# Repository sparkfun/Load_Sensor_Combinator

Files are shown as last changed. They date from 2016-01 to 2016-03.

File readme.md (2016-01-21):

SparkFun Load Sensor Combinator
=============================

SparkFun Load Sensor Combinator

[*SparkFun Load Sensor Combinator (BOB-13281)*](https://www.sparkfun.com/products/13281)

Repository Contents
-------------------
* **/Hardware** - Eagle design files (.brd, .sch)

Documentation
--------------
* **[Hookup Guide](https://learn.sparkfun.com/tutorials/load-cell-amplifier-hx711-breakout-hookup-guideL)** - Basic hookup guide.
* **[SparkFun Fritzing repo](https://github.com/sparkfun/Fritzing_Parts)** - Fritzing diagrams for SparkFun products.
* **[SparkFun 3D Model repo](https://github.com/sparkfun/3D_Models)** - 3D models of SparkFun products. 

How to Use
----------
Combinator PCB

Combinator PCB in action

If you open up an electronic bathroom scale you’ll find a large rats nest of wires. The Load Sensor Combinator was created to combine the 12 wires found in a bathroom scale into the standard 4-wires that wheatstone bridge configuration.

This board also works with four of our individual [load sensors](https://www.sparkfun.com/products/10245). If you aren’t mechanically inclined we recommend purchasing an off-the-shelf bathroom scale and hacking the combinator into it rather than trying to design a base to properly mount four load sensors.

This board works great with our [Load Cell Amplifier](https://www.sparkfun.com/products/13230) breakout board. The five pins on the edge of the combinator line directly up to the five pins on the amplifier.

If your amplifier and supporting electronics are more than a few inches away from the scale an [RJ45 footprint](https://www.sparkfun.com/products/643) is provided. The 4 wheatstone pins (E+/E-/S+/S-) are connected to twisted pairs within a standard cheap ethernet cable. This allows the amplifier board to be placed many feet away from the scale itself.

The combinator board also includes a footprint for the [DS18B20 one wire temperature sensor](https://www.sparkfun.com/products/245). This allows the user to gather the temperature of the scale in case there is a large variance between the scale and the amplifier. These three pins are exposed to the RJ45 connection as well allowing remote temperature readings to be gathered over one twisted pair ethernet cable.

If you plan to use the RJ45 connection you will need to cut and strip the end of the ethernet cable you do not intend to plug into the combinator board. The wires of the exposed ethernet cable connect to the following pins on the combinator board:

* Combinator Pin = Ethernet cable wire color
* E+ = Brown
* E- = Brown white
* NC = Green
* A+ = Blue white
* A- = Blue
* 5V = Green white
* TEMP_DAT = Orange
* GND = Orange white

The NC pin is intentionally left *not connected*. For especially long cables the signals should be shielded against EMI. This is done by using the less common [shielded twisted pair](http://en.wikipedia.org/wiki/Twisted_pair#Cable_shielding) (STP) ethernet cable. The metal foil sheath of the cable creates a telescoping shield by connecting it to ground on the amplifier circuit, not on GND or any other pin on the combinator board.

License Information
-------------------

This product is _**open source**_! 

Please review the LICENSE.md file for license information. 

If you have any questions or concerns on licensing, please contact techsupport@sparkfun.com.

Distributed as-is; no warranty is given.

- Your friends at SparkFun.

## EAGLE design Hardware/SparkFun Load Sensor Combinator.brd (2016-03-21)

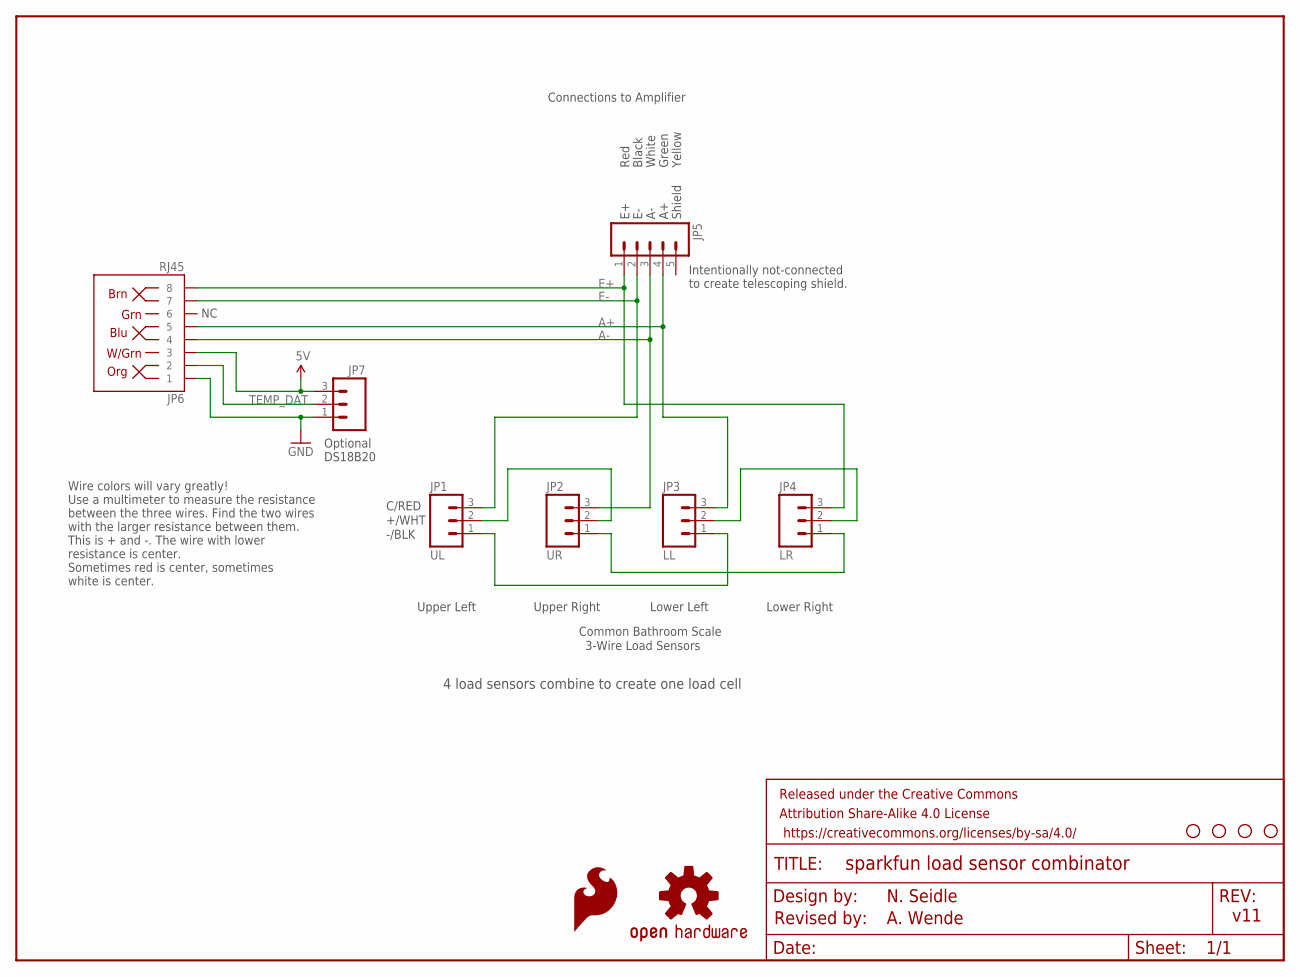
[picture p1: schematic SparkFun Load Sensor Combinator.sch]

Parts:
FRAME1: FRAME-LETTER; CREATIVE_COMMONS
JP1: UL; 1X03
JP2: UR; 1X03
JP3: LL; 1X03
JP4: LR; 1X03
JP5: M05PTH; 1X05
JP6: RJ45; RJ45-8
JP7: M03PTH; 1X03
LOGO3: SFE_LOGO_FLAME.1_INCH; SFE_LOGO_FLAME_.1
STANDOFF1, STANDOFF2, STANDOFF3, STANDOFF4: STAND-OFF
U$7: OSHW-LOGOS; OSHW-LOGO-S

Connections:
5V: JP6.3, JP7.3
A+: JP3.3, JP5.4, JP6.5
A-: JP2.3, JP5.3, JP6.4
E+: JP4.3, JP5.1, JP6.8
E-: JP1.3, JP5.2, JP6.7
GND: JP6.1, JP7.1
unnamed: JP2.1, JP4.1
unnamed: JP1.1, JP3.1
unnamed: JP3.2, JP4.2
unnamed: JP1.2, JP2.2
TEMP_DAT: JP6.2, JP7.2

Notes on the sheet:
Red
Black
White
Green
Lower Right
Upper Right
Lower Left
Upper Left
3-Wire Load Sensors
Common Bathroom Scale
Connections to Amplifier
-/BLK
+/WHT
C/RED
4 load sensors combine to create one load cell
Shield
Yellow
Intentionally not-connected to create telescoping shield.
Optional DS18B20
N. Seidle
v11
Revised by:
A. Wende
Wire colors will vary greatly\! Use a multimeter to measure the resistance between the three wires. Find the two wires with the larger resistance between them. This is + and -. The wire with lower resistance is center. Sometimes red is center, sometimes white is center.

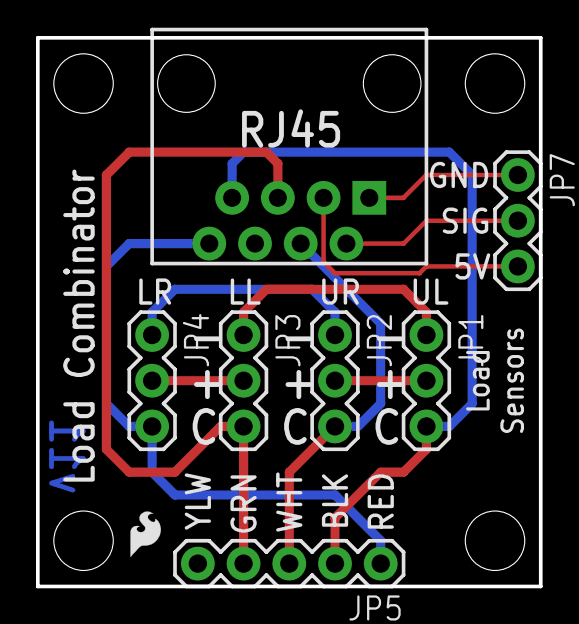
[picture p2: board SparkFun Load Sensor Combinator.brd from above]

Board: 2 copper layers, 27.9 x 30.5 mm, 14 parts (1 on the bottom side), 11 nets.

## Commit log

2015-01-26 Added feedback from Eng review
    Match 5-pin connector on breakout. Add yellow pin with NC. Add note to
    schematic describing that 4 sensors create one load cell.
    [SparkFun Load Sensor Combinator.brd, SparkFun Load Sensor Combinator.sch]
2015-01-26 Added dimensions.
    [SparkFun Load Sensor Combinator.brd, SparkFun Load Sensor Combinator.sch]
2015-01-30 Added RJ45
    [SparkFun Load Sensor Combinator.brd, SparkFun Load Sensor Combinator.sch]
2015-01-30 Added dims
    [SparkFun Load Sensor Combinator.brd]
2015-01-30 Added DS18S20 connection.
    [SparkFun Load Sensor Combinator.brd, SparkFun Load Sensor Combinator.sch]
2015-01-30 Correcting name to DS18B20
    [SparkFun Load Sensor Combinator.brd, SparkFun Load Sensor Combinator.sch]
2015-02-04 Bumped silk and rev 02
    Fixed issue #1
    [SparkFun Load Sensor Combinator.brd, SparkFun Load Sensor Combinator.sch]
2015-03-25 Fixed a swap between A+ and A-
    [SparkFun Load Sensor Combinator.brd, SparkFun Load Sensor Combinator.sch]
2015-04-09 Update silk
    [SparkFun Load Sensor Combinator.brd]
2015-04-09 Update schematic version
    [SparkFun Load Sensor Combinator.brd, SparkFun Load Sensor Combinator.sch]
2015-04-10 Adding 5V and GND symbols to schematic.
    [SparkFun Load Sensor Combinator.sch]
2015-05-27 Changed silk from BLK to -, WHT to C.
    [SparkFun Load Sensor Combinator.brd, SparkFun Load Sensor Combinator.sch]
2015-06-10 Updated version on PCB to v11
    v11 changes the silk from R/W/B to more generic and easier to understand
    +/C/-
    [SparkFun Load Sensor Combinator.brd]
2015-06-10 Updates to readme with new photos and description
    [SparkFun Load Sensor Combinator.sch]
2015-08-27 Cleaning up repo structure, adding license file
    [SparkFun Load Sensor Combinator.brd, SparkFun Load Sensor Combinator.sch]
2015-08-27 Reverting Eagle files back to what is being sold on store front
    [SparkFun Load Sensor Combinator.brd, SparkFun Load Sensor Combinator.sch]
2016-03-21 Revision 11 changes
    Updated labels from R/W/B to +/-/C and moved temp sensor pins down away
    from standoff.
    [SparkFun Load Sensor Combinator.brd, SparkFun Load Sensor Combinator.sch]

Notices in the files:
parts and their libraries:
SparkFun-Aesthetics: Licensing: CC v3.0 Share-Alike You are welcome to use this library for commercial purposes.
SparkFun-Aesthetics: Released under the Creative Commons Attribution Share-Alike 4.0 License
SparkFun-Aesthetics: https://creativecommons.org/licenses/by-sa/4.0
